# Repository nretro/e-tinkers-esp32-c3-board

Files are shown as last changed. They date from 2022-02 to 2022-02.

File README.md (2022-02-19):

# USB_JTAG mod of E-Tinkers ESP32-C3 Board

The ESP32-C3 chip has a USB to JTAG bridge built in, but no dev board directly makes use of it. So I modified
Henry Cheung's breakout board

The main differences are:
  * micro USB connector with ESD protection (CM1231)
  * different LDO (TLV76733DRVR)
  * removed the flash button (not needed when using JTAG)
  * modified some footprints:
	* all necessary resistors and capacitors have 0805 footprints, which also allows to use 0603 parts
	* deleted the antenna from the module footprint since that interferes with panelizing 
	* stretched pads of the WS2812 footprint to aid hand soldering

Options:
  * added optional 22pF capacitors to D+ and D- lines on the bottom. They appear on the schematics of the official dev board, but seem not to be necessary.
  * populating R4 with a 0 ohm resistor will connect USB shield with GND. Usually shield is connected to GND at the host and not at devices downstream. Therefore R4 should be left unpopulated in most applications. 
  * the LDO can be disabled by connecting LDO_EN to GND to save energy when not used.

Please note that since I made some minor modifications after receiving
the first patch of PCBs, I have not yet used the gerbers in the
archive to fabricate actual boards. Therefore there is a small chance
that those contain errors.

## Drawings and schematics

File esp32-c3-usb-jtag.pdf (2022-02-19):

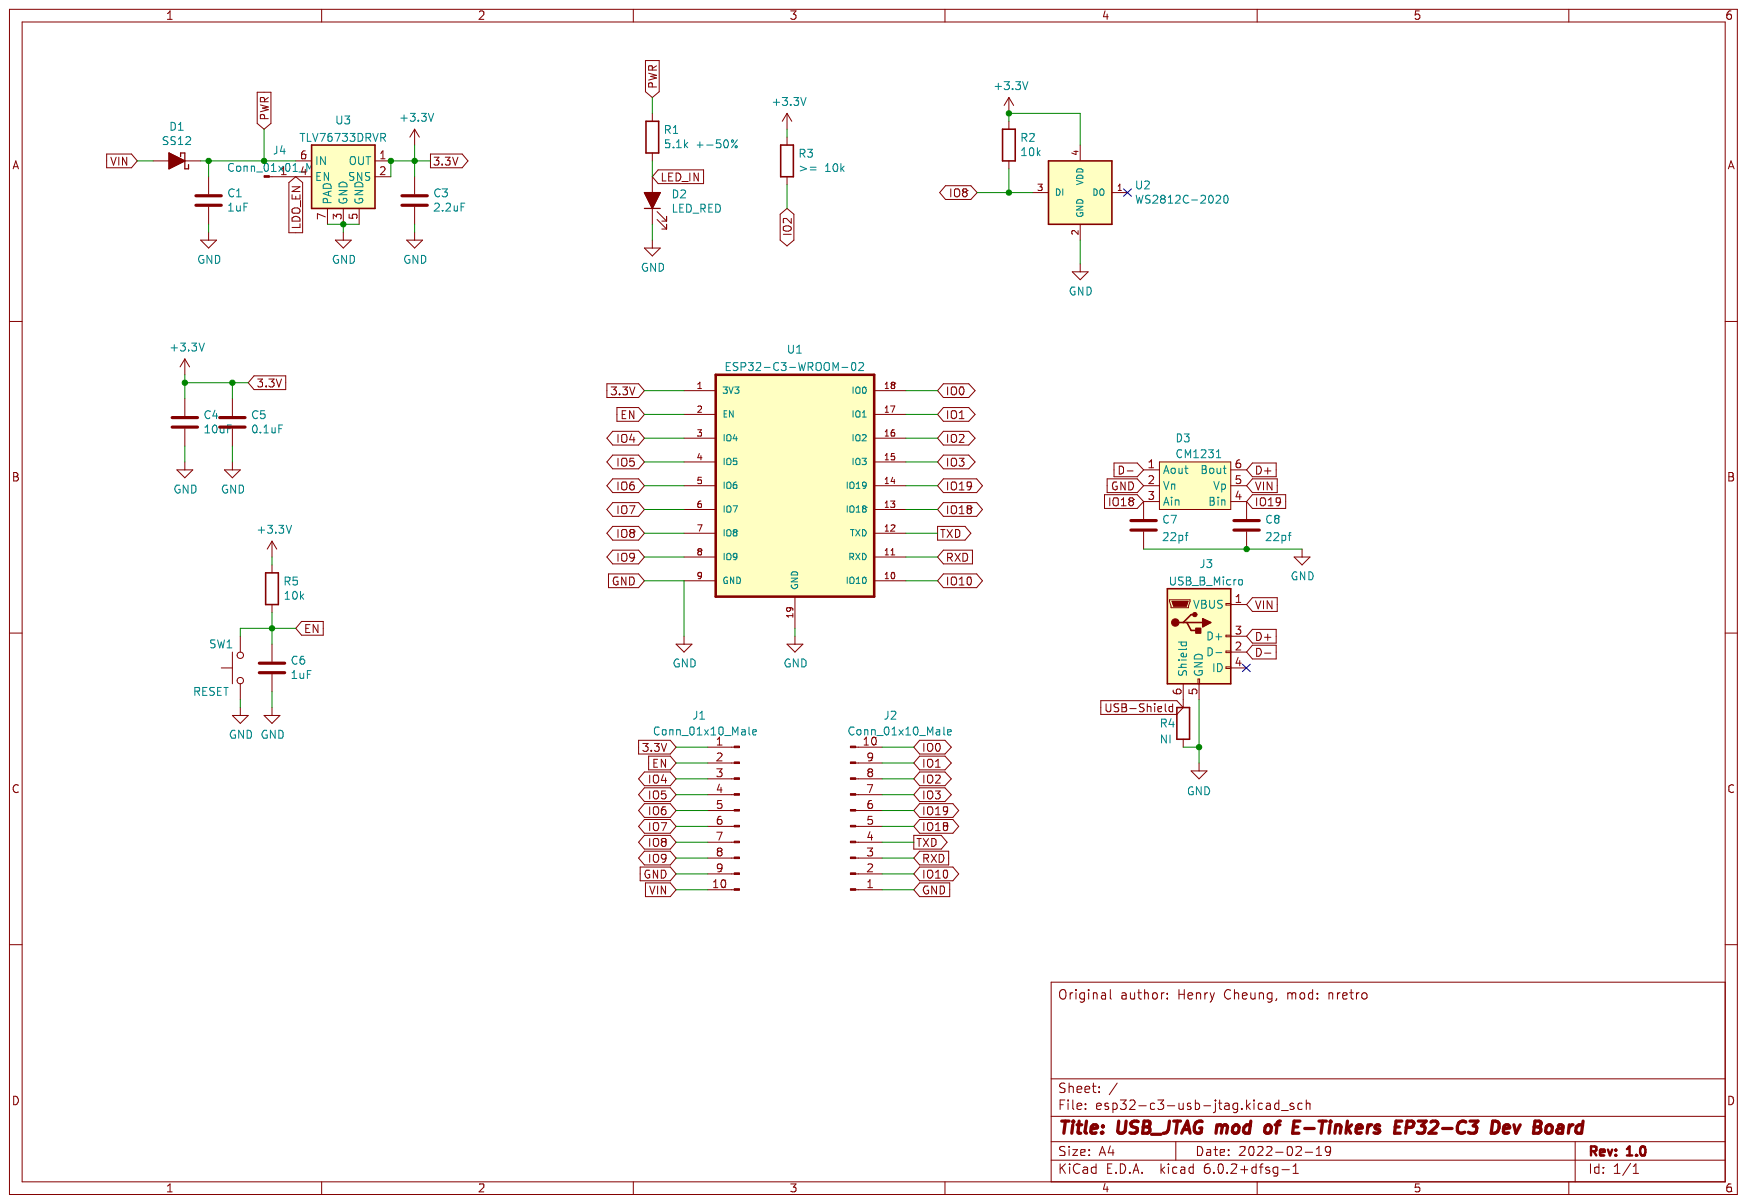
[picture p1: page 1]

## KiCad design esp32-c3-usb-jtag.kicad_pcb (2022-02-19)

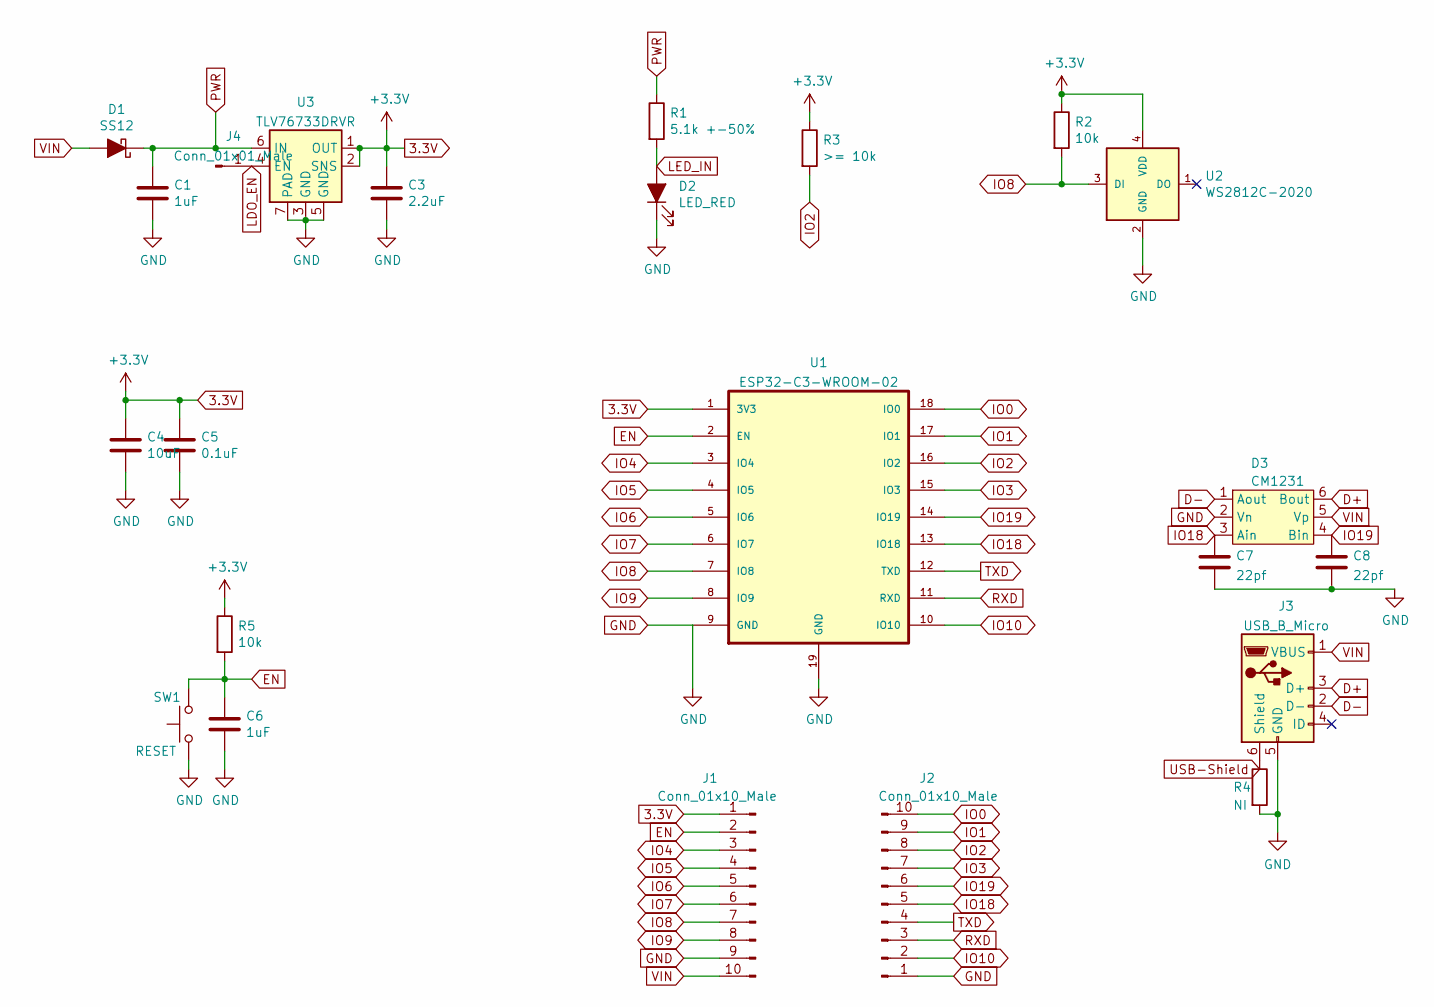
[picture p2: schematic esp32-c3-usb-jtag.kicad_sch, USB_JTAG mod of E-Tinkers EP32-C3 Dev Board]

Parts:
C1, C6: 1uF; C_0805_2012Metric
C3: 2.2uF; C_0805_2012Metric
C4: 10uF; C_0805_2012Metric
C5: 0.1uF; C_0805_2012Metric
C7, C8: 22pf; C_0603_1608Metric
D1: SS12; D_SMA
D2: LED_RED; LED_0805_2012Metric
D3: CM1231; SOT-23-6_Handsoldering
J1, J2: Conn_01x10_Male; PinHeader_1x10_P2.54mm_Vertical
J3: USB_B_Micro; USB_Micro-B_China
J4: Conn_01x01_Male; PinHeader_1x01_P2.54mm_Vertical
R1: 5.1k +-50%; R_0603_1608Metric_Pad1.05x0.95mm_HandSolder
R2, R5: 10k; R_0603_1608Metric_Pad1.05x0.95mm_HandSolder
R3: >= 10k; R_0603_1608Metric_Pad1.05x0.95mm_HandSolder
R4: NI; R_0603_1608Metric
SW1: RESET; SW_TS-1185-X-X
U1: ESP32-C3-WROOM-02; ESP32-C3-WROOM-02_ant
U2: WS2812C-2020; LED_WS2812C-2020_hand
U3: TLV76733DRVR; WSON-6-1EP_2x2mm_P0.65mm_EP1x1.6mm_ThermalVias

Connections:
3.3V: C3.1, C4.1, C5.1, J1.1, R2.1, R3.1, R5.1, U1.1 (3V3), U2.4 (VDD), U3.1 (OUT), U3.2 (SNS)
D+: D3.6 (Bout), J3.3 (D+)
D-: D3.1 (Aout), J3.2 (D-)
EN: C6.1, J1.2, R5.2, SW1.2, U1.2 (EN)
GND: C1.2, C3.2, C4.2, C5.2, C6.2, C7.2, C8.2, D2.1 (K), D3.2 (Vn), J1.9, J2.1, J3.5 (GND), R4.2, SW1.1, U1.9 (GND), U1.19 (GND), U2.2 (GND), U3.3 (GND), U3.5 (GND), U3.7 (PAD)
IO0: J2.10, U1.18 (IO0)
IO1: J2.9, U1.17 (IO1)
IO2: J2.8, R3.2, U1.16 (IO2)
IO3: J2.7, U1.15 (IO3)
IO4: J1.3, U1.3 (IO4)
IO5: J1.4, U1.4 (IO5)
IO6: J1.5, U1.5 (IO6)
IO7: J1.6, U1.6 (IO7)
IO8: J1.7, R2.2, U1.7 (IO8), U2.3 (DI)
IO9: J1.8, U1.8 (IO9)
IO10: J2.2, U1.10 (IO10)
IO18: C7.1, D3.3 (Ain), J2.5, U1.13 (IO18)
IO19: C8.1, D3.4 (Bin), J2.6, U1.14 (IO19)
LDO_EN: J4.1, U3.4 (EN)
LED_IN: D2.2 (A), R1.2
unnamed: J3.6 (Shield), R4.1
PWR: C1.1, D1.1 (K), R1.1, U3.6 (IN)
RXD: J2.3, U1.11 (RXD)
TXD: J2.4, U1.12 (TXD)
VIN: D1.2 (A), D3.5 (Vp), J1.10, J3.1 (VBUS)

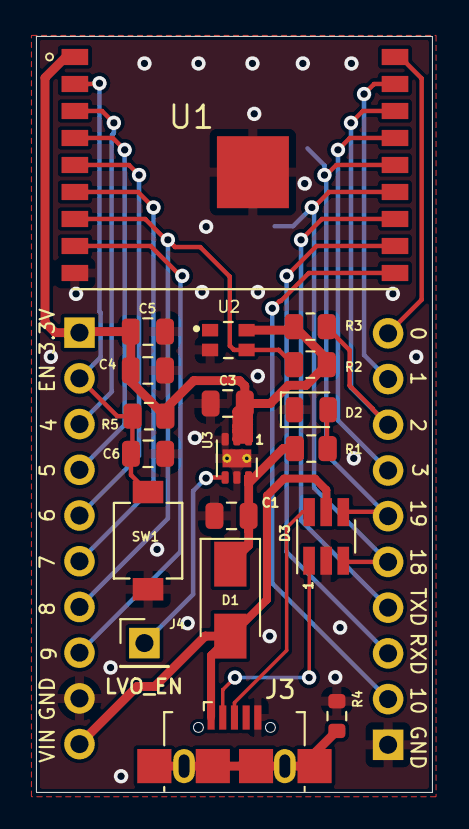
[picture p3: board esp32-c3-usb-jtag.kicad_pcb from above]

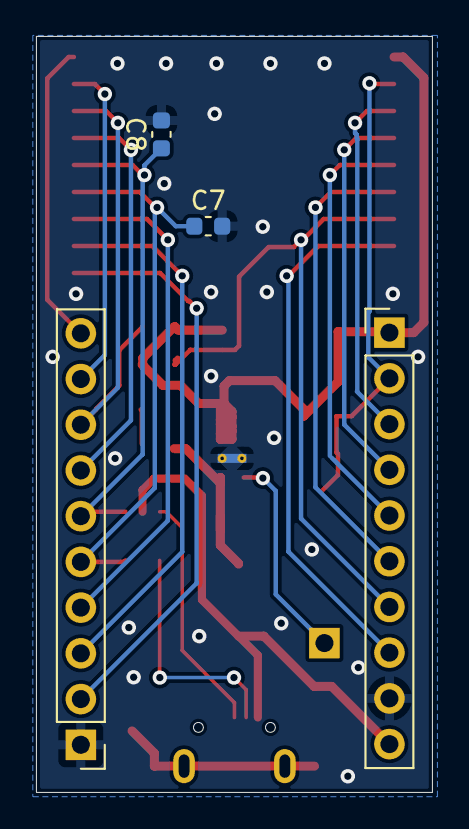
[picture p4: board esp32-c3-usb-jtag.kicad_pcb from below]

Board: 2 copper layers, 22.0 x 42.0 mm, 23 parts (4 on the bottom side), 25 nets.
